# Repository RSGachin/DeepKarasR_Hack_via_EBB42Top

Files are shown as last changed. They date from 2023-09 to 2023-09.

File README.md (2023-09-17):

# DeepKarasR_Hack_via_EBB42Top
Версия дип карася от //Hack переделанная под [топ с EBB42](https://github.com/RSGachin/DeepKarasR_Hack_via_EBB42/tree/main/DeepKarasR_Hack_via_EBB42Top) для BIQU H2V2S/BIQU H2.(Низ сборки никак не изменялся!)
>[!Warning]
>После распечатывания нижней части ***обязательно*** удалить поддержку с флажка концевика, иначе при парковке очень велик шанс что флажок снесет SMD компоненты на оптическом концевике!

> [!IMPORTANT]
> В процессер сборки EBB42 устанавливать в ***последнюю очередь***! Сначала просунуть все разьемы, прикрутить провода нагревателя к плате, и только потом прикручивать EBB42 непосредственно к голове!

Так же в сборку добавлен держатель кабеля от [Зохана](https://www.thingiverse.com/thing:5883228).  
Конфиг BL-Touch искать [тут](https://github.com/RSGachin/DeepKarasR_Hack_via_EBB42/blob/main/DeepKarasR_Hack_v4/Readme.md).  

> [!NOTE]
> Топ выполнен на основе STEP файла от первой версии дип карася с [гита ТомТомыча](https://github.com/Tombraider2006/klipperFB6/blob/main/karas/readme.md). Поэтому все изменения касающиеся топа от [//Hack](https://github.com/RSGachin/DeepKarasR_Hack_via_EBB42Top/blob/main/DeepKarasR_Hack_v4/Readme.md) тут ***отсутствуют***, вырезы под рычаг фиксации филамента сделаны заново.

Оригинальная версия дип карася от //Hack [DeepKarasR_Hack_v4](https://github.com/RSGachin/DeepKarasR_Hack_via_EBB42/tree/main/DeepKarasR_Hack_v4) и [тут](https://t.me/Biquh2_4_fbg6/28567)

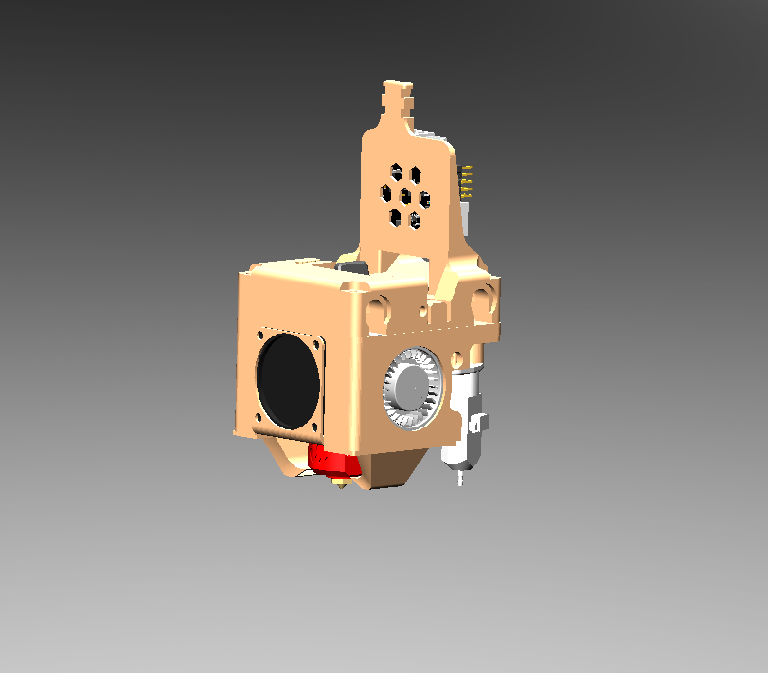
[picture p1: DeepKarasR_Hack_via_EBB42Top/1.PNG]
Спереди
  
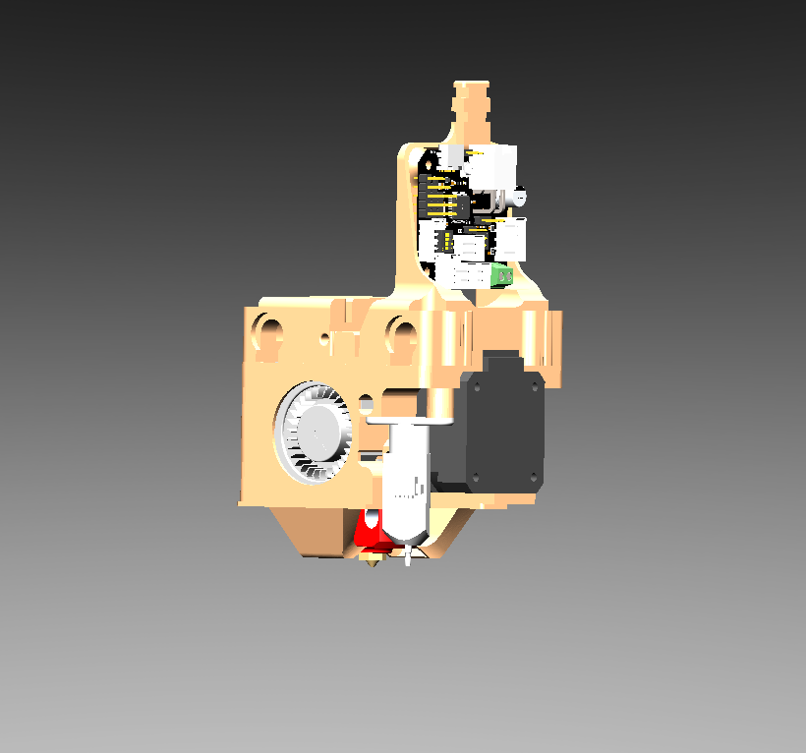
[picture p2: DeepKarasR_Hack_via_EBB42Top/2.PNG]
Сзади
  
Фото:  
  
  
  
  

--------------------------------------------------------

--------------------------------------------------------

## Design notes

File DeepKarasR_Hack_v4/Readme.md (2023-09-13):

# Версия дип карася от //Hack, вверх под родную переходную плату.(Ниже комментарии от автора которые я смог найти):  
"Решил немного переделать проект DeepKarasR. Из всех проектов под Biqu H2 этот мне понравился больше всех, но считаю, что ему не хватает нескольких технических доработок. О них ниже."  
v1  
Мои изменения:
1. Кабель-менеджмент стал гораздо проще. Теперь не надо сидеть с мотком проводов и висящими вентиляторами, пытаясь установить непосредственно сам экструдер. Теперь для замены проводки достаточно снять только правый вентилятор. Еще может понадобится открутить немного два винта под этим вентилятором, чтоб иметь возможность отогнуть правую часть головы для прокладки проводов под BL-Touch и вентилятора радиатора;
2. Убрана часть правой стенки для кабель-менеджмента, но усилена правая стенка на 1 периметр (0,4мм). Жесткость при этом не теряется, так как в качестве ребра жесткости выступает сопло обдува, прикрученное винтами;
3. Изменены диаметры всех отверстий с учетом погрешности печати. Теперь где надо - винтики проходят свободно, а где надо - нормально закручиваются и не вызывают трещин;
4. Увеличена глубина отверстий до 10мм под сопла обдува, так как 5мм в оригинале мало, а у меня все винтики были на 8 и на 10мм в длину;
5. Изменены немного кабель-каналы. Провода в них стало просунуть легче, при этом сами они стали более жесткими, на оригинале они у меня отламывались на раз-два.
6. Увеличена толщина так называемого в оригинале WireHolder на 0,2 мм. Теперь он стал жестче и не пытается сломаться при любом удобном случае. На габариты головы никак не влияет.

Размеры головы стали больше в правую сторону на 0,4 мм. Также я убрал все надписи и логотипы, так как не люблю оные на вещах."  

v2  
"Вот и вторая версия моего Карася. Полностью переработана модель. Теперь обе дуйки вынесены вперед. Я добивался максимально правильного воздушного потока. Эффективность выроста почти вдвое по сравнению с обычным DeepKaras, благодаря форме дуек и их расположению. Bl-Touch вынесен назад. Он теперь не выходит за пределы корпуса. Но пришлось пожертвовать удобством монтажа. Несколько упростил проводку. Плата головы теперь горизонтальна, защиту для нее еще не смоделировал. Если кого-то не устраивает такое расположение платы по тем или иным причинам, то печатайте TopPart из первой версии. Зона печати X253 x Y210 x Z210. Следующим сообщением напишу необходимые параметры для BL-Touch."  

v3  
"Третья версия Карася в моем исполнении. Основные отличия от второй - это работа над ошибками в нижней части, совместимость с BiQU H2 V2s (за что огромное спасибо @Yacek77, все расчеты передал мне он) и немного расширены посадочные места под подшипники. 
Теперь установка гораздо легче. Также изменены упоры под подшипники.
Но лично я от них совсем отказался, так как подшипники встают очень плотно, а упоры в 0,1 мм очень сложно печатать.   
Вероятнее всего, это последняя версия."  

v4  
"Ничего особенного не сделал.
У меня оказались отверстия на правой дуйке не соосны. 
То есть достаточно перепечатать только правую дуйку, если кто-то испытывает  проблемы."  

"Это параметры для прошивки Klipper. Если у вас марлин, то интерпретируйте просто настройки из тех, что ниже на свой конфиг.   
[bltouch]  
x_offset: 25  
y_offset: 31  
  
[screws_tilt_adjust]  
screw1: 3,0   
screw1_name: front left screw  
screw2: 3,150  
screw2_name: back left screw  
screw3: 203,150  
screw3_name: back right screw  
screw4: 203,0  
screw4_name: front right screw  
  
[safe_z_home]  
home_xy_position: 102,74    
  
[bed_mesh]  
mesh_min: 25,36  
mesh_max: 230,174  
 
"  
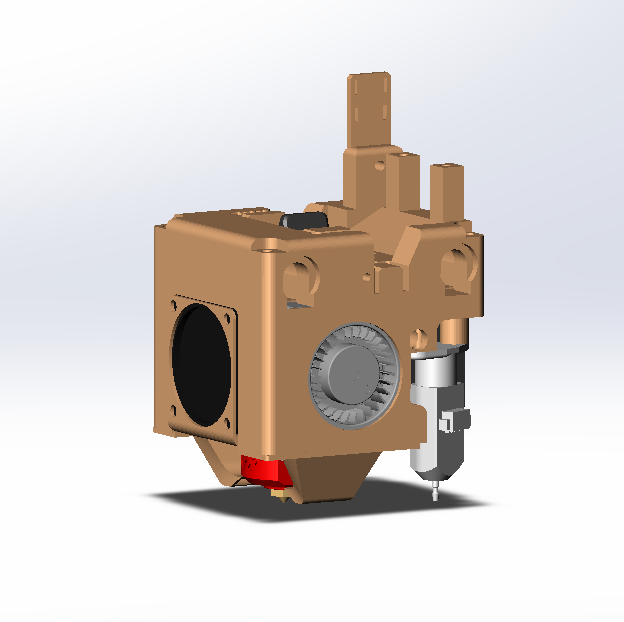
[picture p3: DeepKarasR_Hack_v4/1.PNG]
  
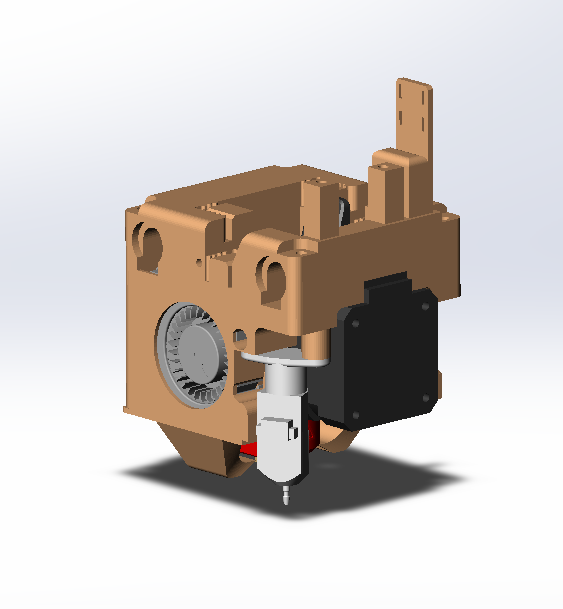
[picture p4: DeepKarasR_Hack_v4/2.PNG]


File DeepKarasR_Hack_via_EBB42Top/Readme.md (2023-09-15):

Верх сделан под плату EBB42 с нуля из обычного карася.  
Низ использован весь от //Hack.  

Печатается без поддержек.  
Стенок 4, слоев 4, заполнение 25%, слой 0.1, скорость 30 мм/с, масштаб 100.35(подбирать индивидуально!)  
Удалить поддержку флажка концевика!  
Удалить поддерживающую перегородку в нижней части!(подробнее в постах //Hack о версиях головы)  
EBB42 устанавливать после того как соберете и протащите все разьемы и провода, привернув к ней провода нагревателя.  
Провода от тача и шаговика дополнительно фиксировал каптоновым скотчем.  
Мотор на BIQU перевернуть на 90 градусов разобрав со стороны радиатора хотенда.

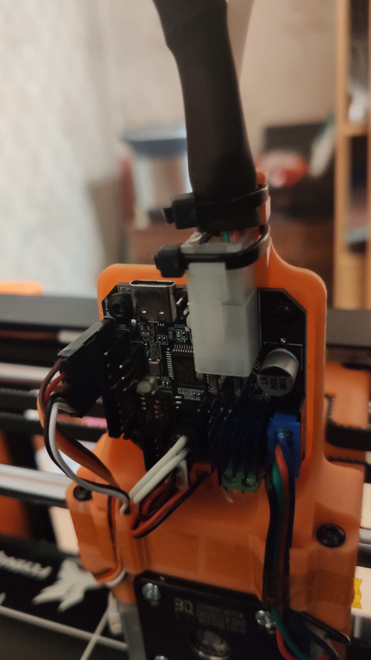
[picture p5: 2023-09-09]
Viev_foto/foto6.JPG

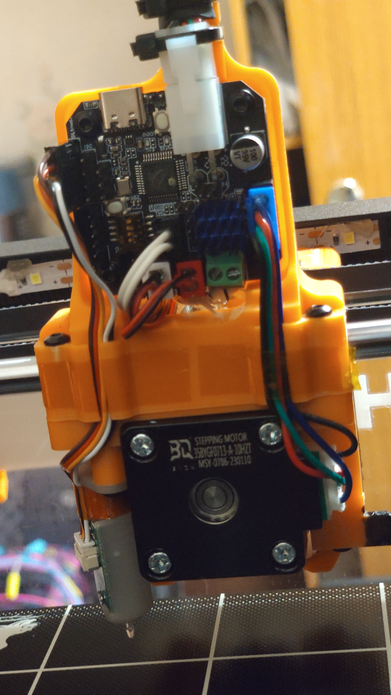
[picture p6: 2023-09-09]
Viev_foto/foto5.JPG

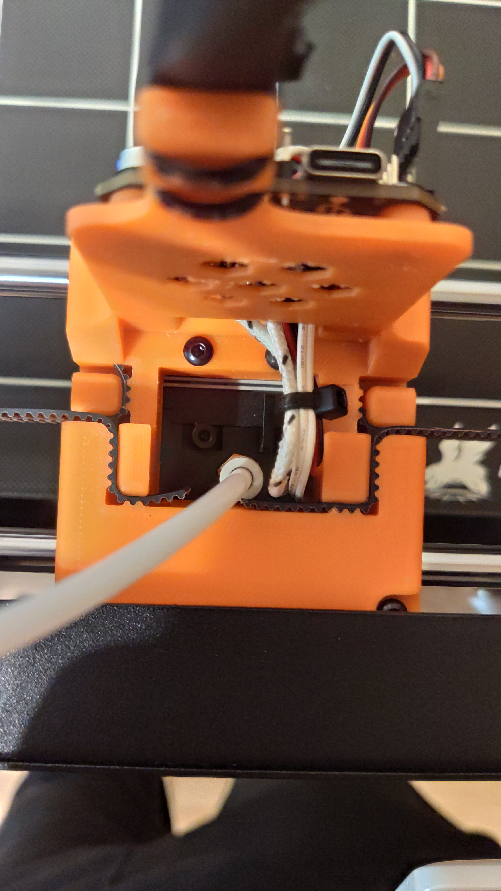
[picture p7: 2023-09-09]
Viev_foto/foto7.JPG

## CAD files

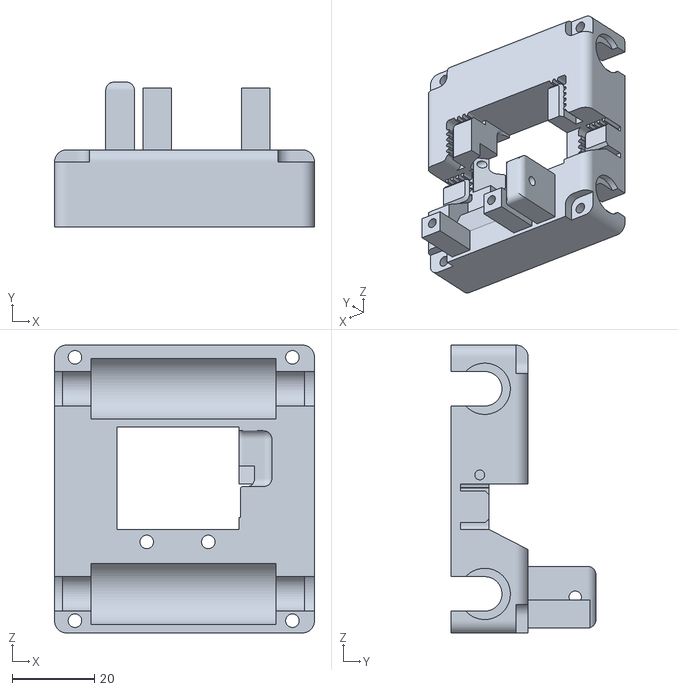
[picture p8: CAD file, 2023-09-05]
DeepKarasR_Hack_v4/TopPart.STL
63.4 x 35.3 x 70.2

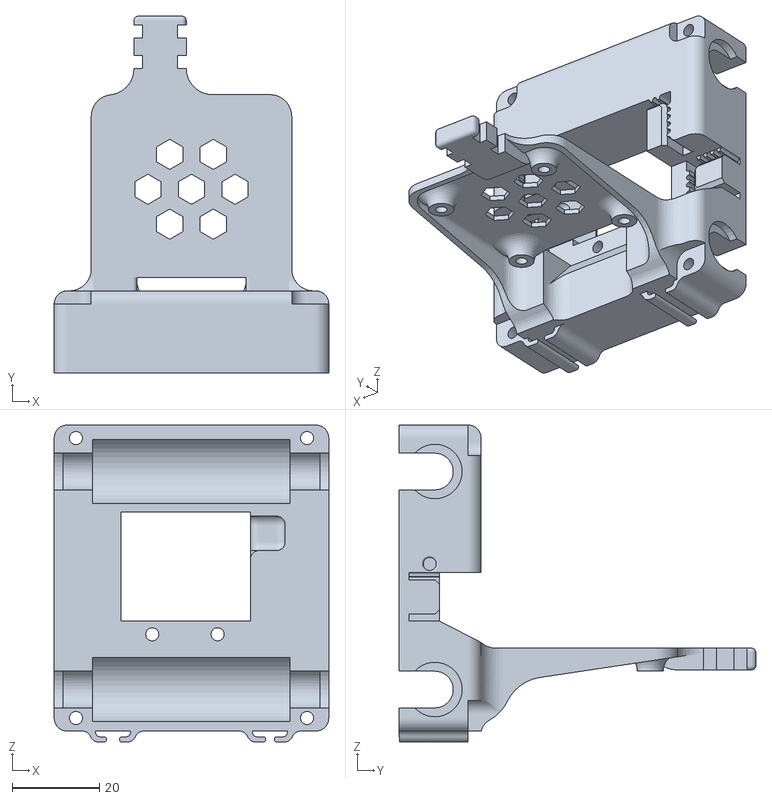
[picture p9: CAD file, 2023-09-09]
DeepKarasR_Hack_via_EBB42Top/TopPartKarasEBB42_V1.3.STL
63.0 x 81.8 x 72.7

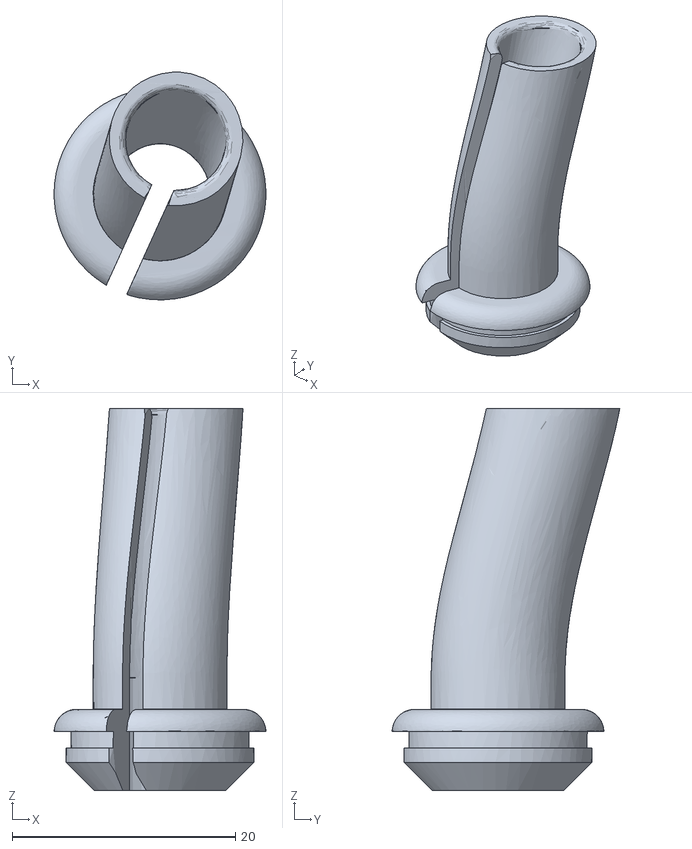
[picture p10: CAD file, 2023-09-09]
DeepKarasR_Hack_via_EBB42Top/Cabel_Holder_by_zohan2.stl
19.0 x 20.4 x 34.2

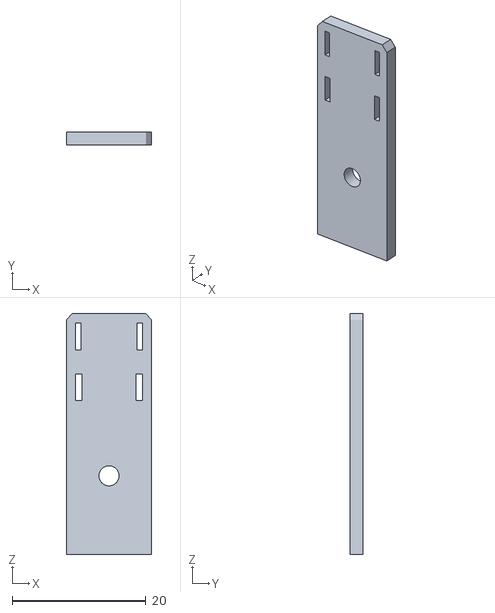
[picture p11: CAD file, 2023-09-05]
DeepKarasR_Hack_via_EBB42Top/Stick.STL
12.8 x 2.00 x 36.0

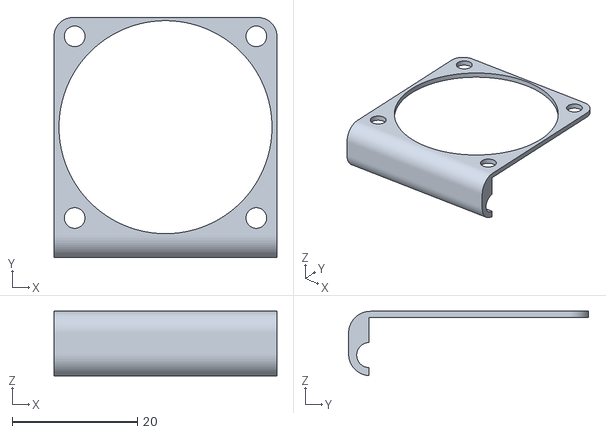
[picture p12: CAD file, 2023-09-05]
DeepKarasR_Hack_via_EBB42Top/WireHolder.STL
35.6 x 38.3 x 10.3

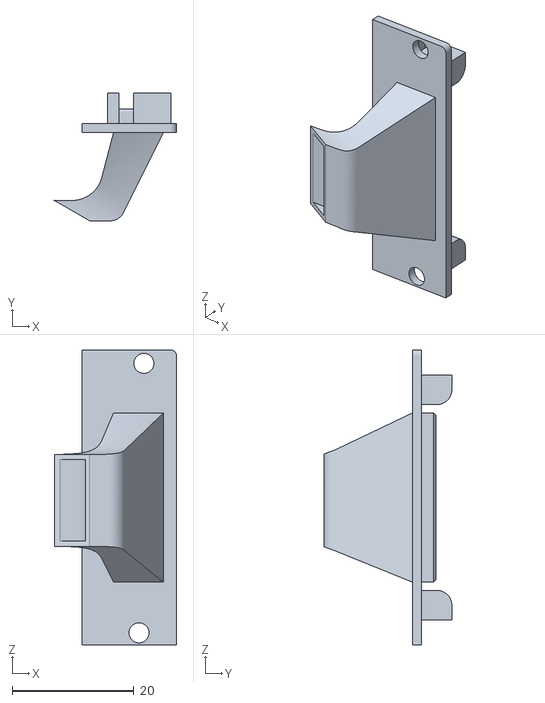
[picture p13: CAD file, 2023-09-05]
DeepKarasR_Hack_via_EBB42Top/NozzleR.STL
20.1 x 21.0 x 48.5

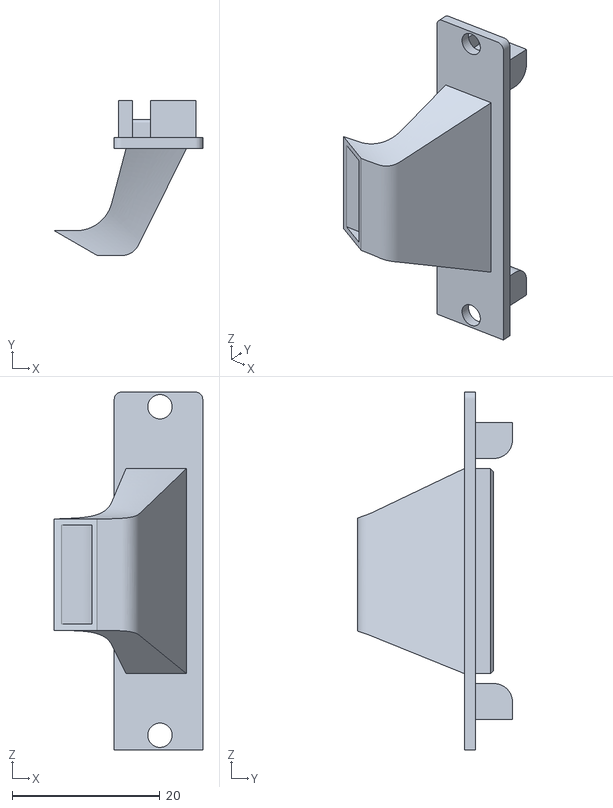
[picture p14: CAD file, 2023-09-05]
DeepKarasR_Hack_via_EBB42Top/NozzleL.STL
20.1 x 21.0 x 48.5

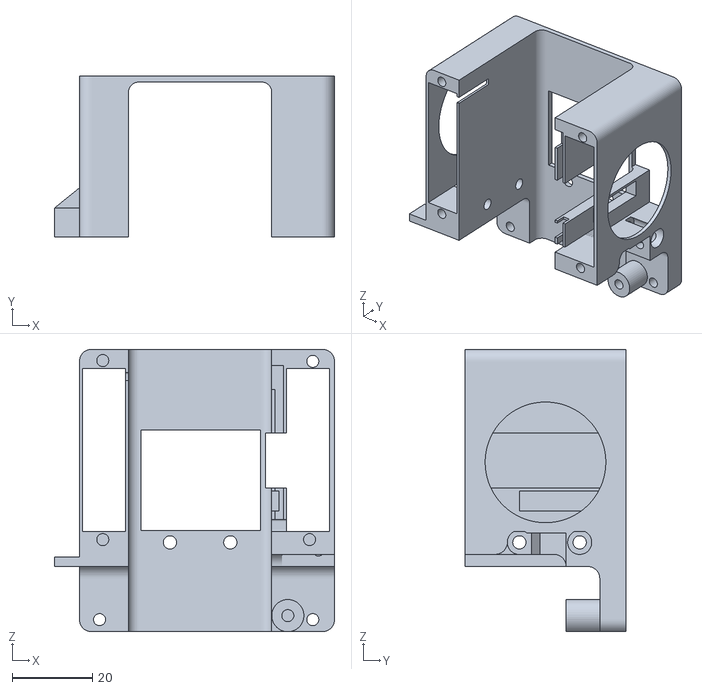
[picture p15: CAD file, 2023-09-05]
DeepKarasR_Hack_via_EBB42Top/BottomPart.STL
69.6 x 40.0 x 70.2

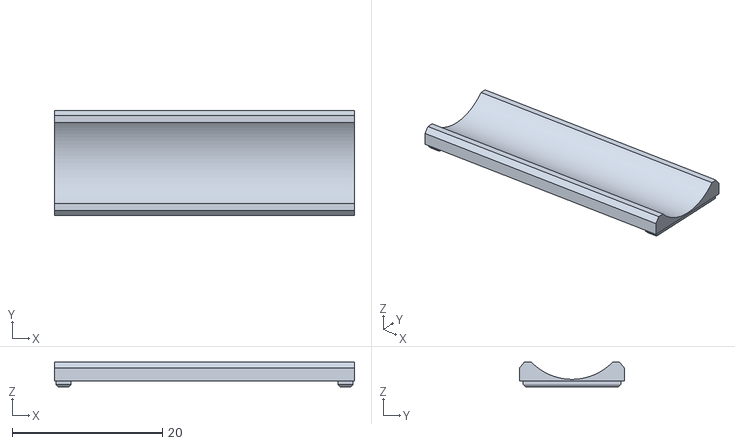
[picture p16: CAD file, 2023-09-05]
DeepKarasR_Hack_via_EBB42Top/Linear.STL
40.0 x 14.0 x 3.32
